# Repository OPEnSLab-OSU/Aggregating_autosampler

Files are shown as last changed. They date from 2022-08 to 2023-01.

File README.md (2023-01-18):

# Aggregating_autosampler
Compositing autosampler using weight based sampling targeted for sewage sampling in manholes. Code originally housed in ADS1232 branch of [SingleSampler repository](https://github.com/OPEnSLab-OSU/SingleSampler) and created using [Kawin Pechetratanapanit's sampler framework](https://github.com/OPEnSLab-OSU/OPEnSamplerFramework).

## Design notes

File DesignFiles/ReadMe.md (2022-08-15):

[Bill of Materials](https://docs.google.com/spreadsheets/d/12LoKV3FAbf4hfWeB7zsqfaazoJ8oWiLxr8qu5_F6xMY/edit?usp=sharing)

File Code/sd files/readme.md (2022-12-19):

Read me for formatting and understanding the data.csv file

data.csv should be opened in Google Sheets or MS Excel (or a similar program) 
for proper readability.

Data.csv logs major milestones in the sampling routine.

The first column of data.csv is the time. It is in unformatted Unix Epoch Time, 
meaning it shows up as a big number representing the number of seconds since 1970.
To convert that big number into a human readable format, make a fourth column that
uses this formula:

=A1/86400+date(1970,1,1)

The second (B) column is the action performed.

Additional columns contain values from the sensors: 
C: Load in grams
D: Temperature in degrees Celsius
E: Pressure in mbar

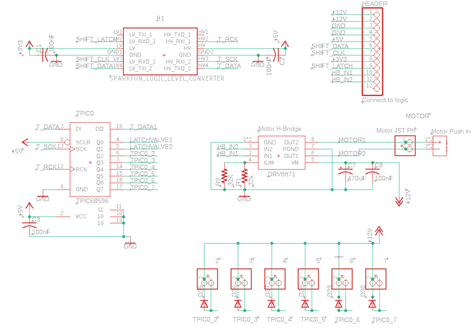
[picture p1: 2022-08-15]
DesignFiles/Power_module_schematic.png

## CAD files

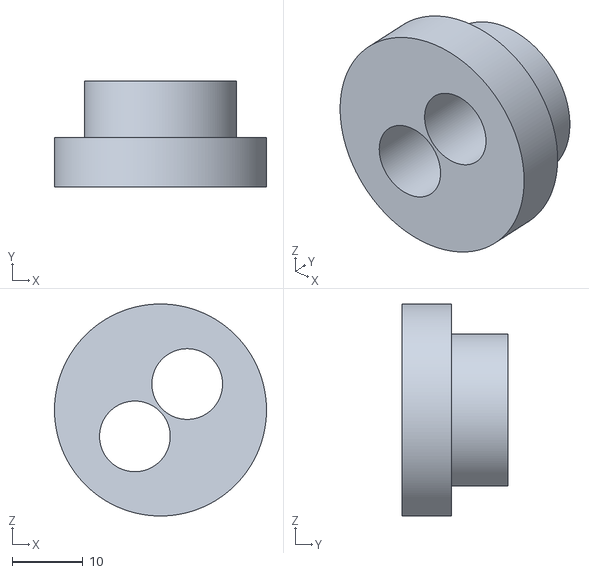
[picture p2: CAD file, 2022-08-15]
DesignFiles/Tube holder.stl
30.0 x 15.0 x 30.0

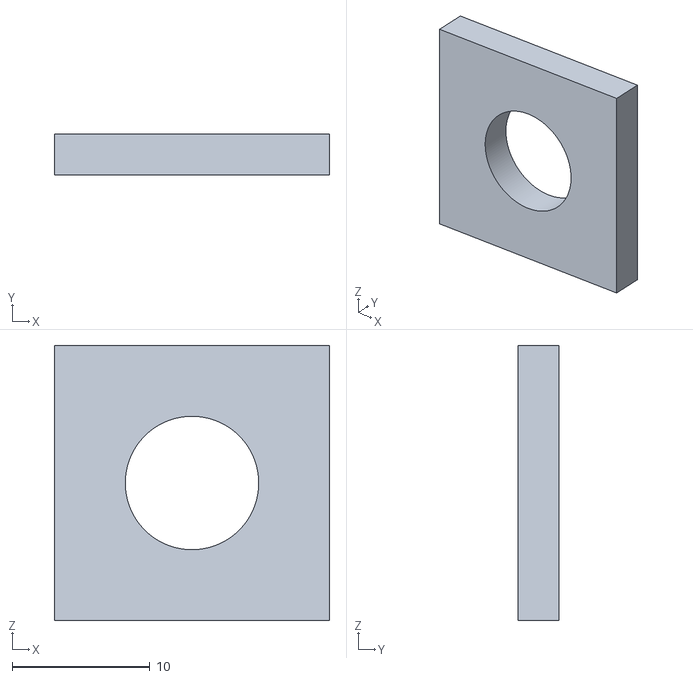
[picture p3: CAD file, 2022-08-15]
DesignFiles/LED Box.stl
20.0 x 3.00 x 20.0

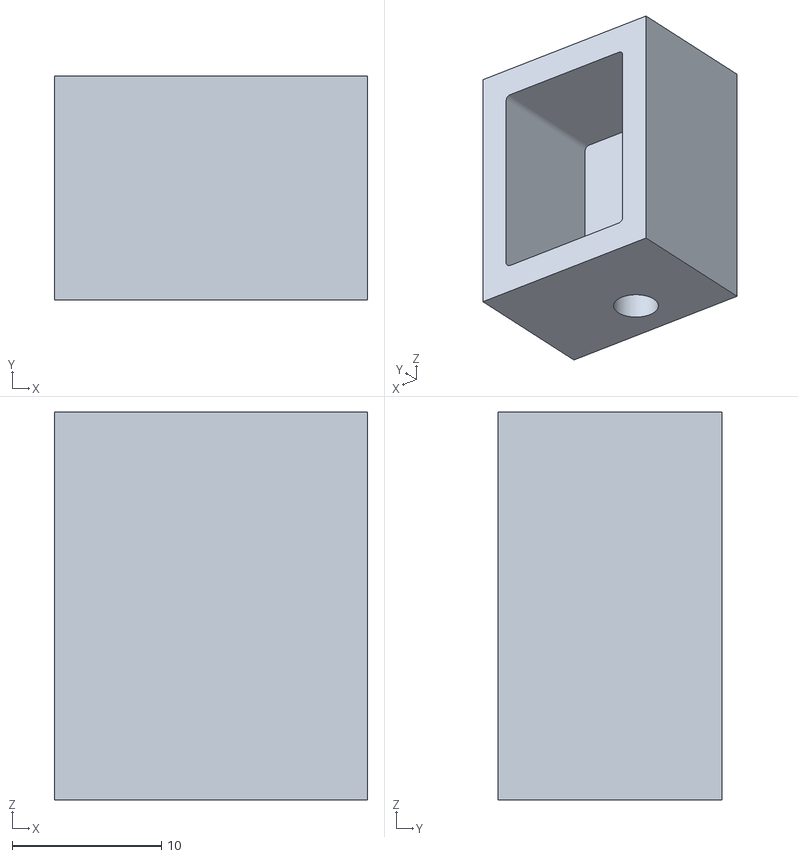
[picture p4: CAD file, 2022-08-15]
DesignFiles/pressure sensor Box.stl
21.0 x 15.0 x 26.0

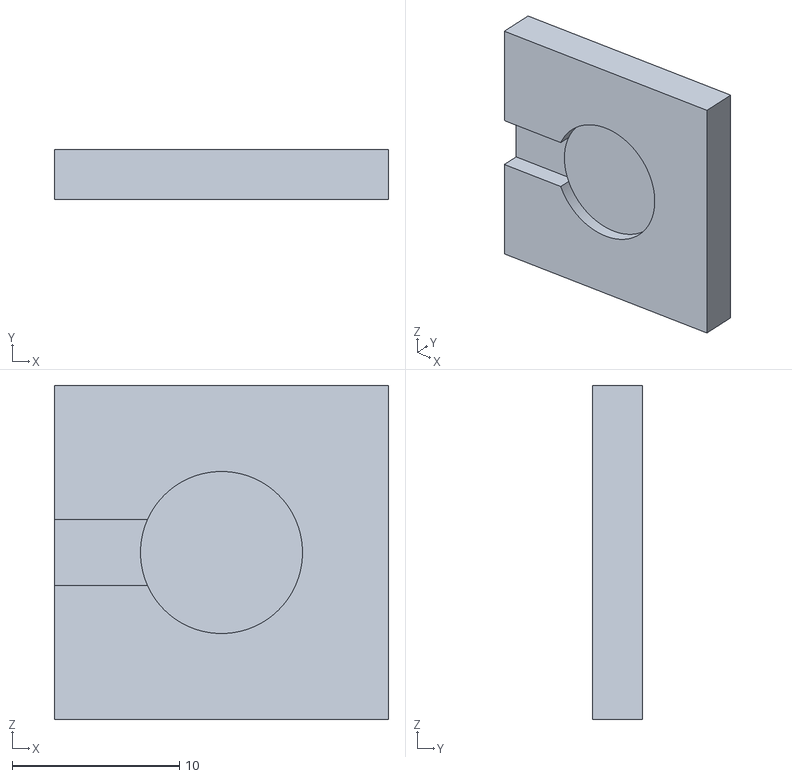
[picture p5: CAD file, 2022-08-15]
DesignFiles/LED Lid.stl
20.0 x 3.00 x 20.0

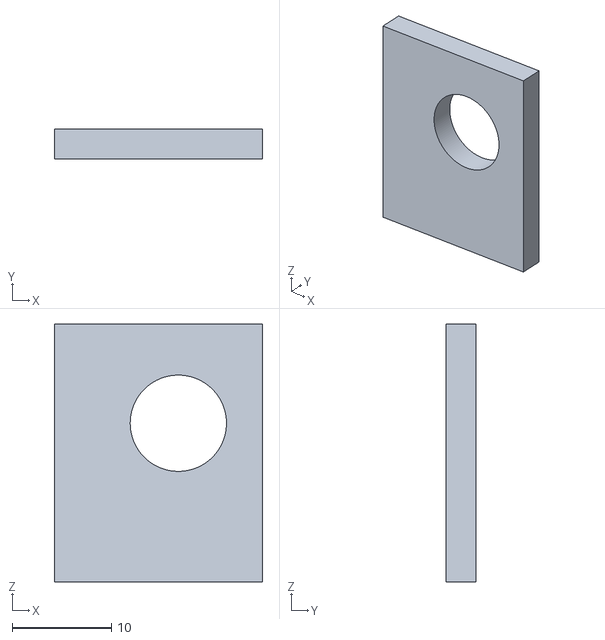
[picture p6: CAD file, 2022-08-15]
DesignFiles/pressure sensor Box lid.stl
21.0 x 3.00 x 26.0

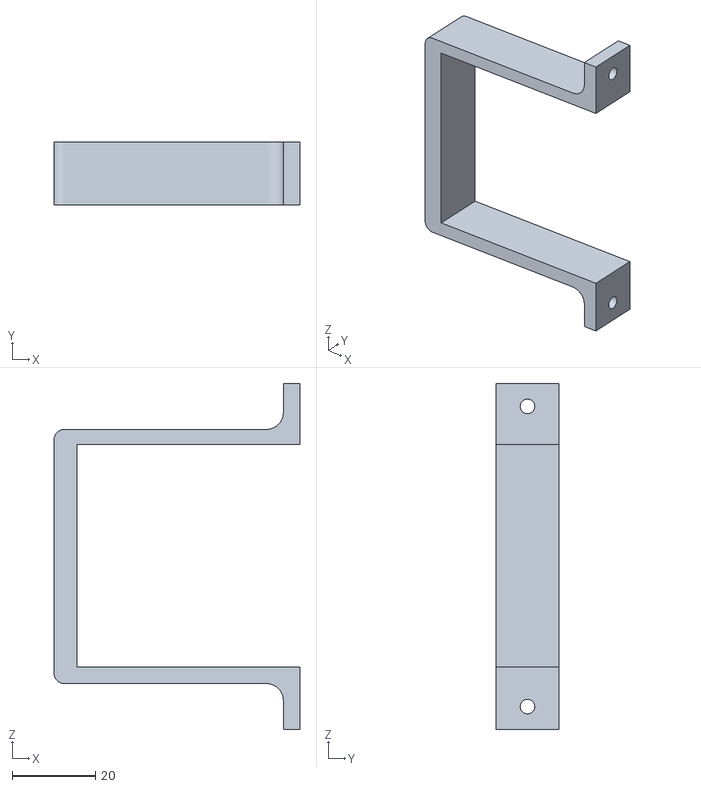
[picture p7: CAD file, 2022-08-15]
DesignFiles/Valve Bracket.stl
59.0 x 15.0 x 83.0

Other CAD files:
DesignFiles/AcrylicCircle.dxf
DesignFiles/Enclosure_insert.dxf
DesignFiles/Enclosure_bottom.dxf

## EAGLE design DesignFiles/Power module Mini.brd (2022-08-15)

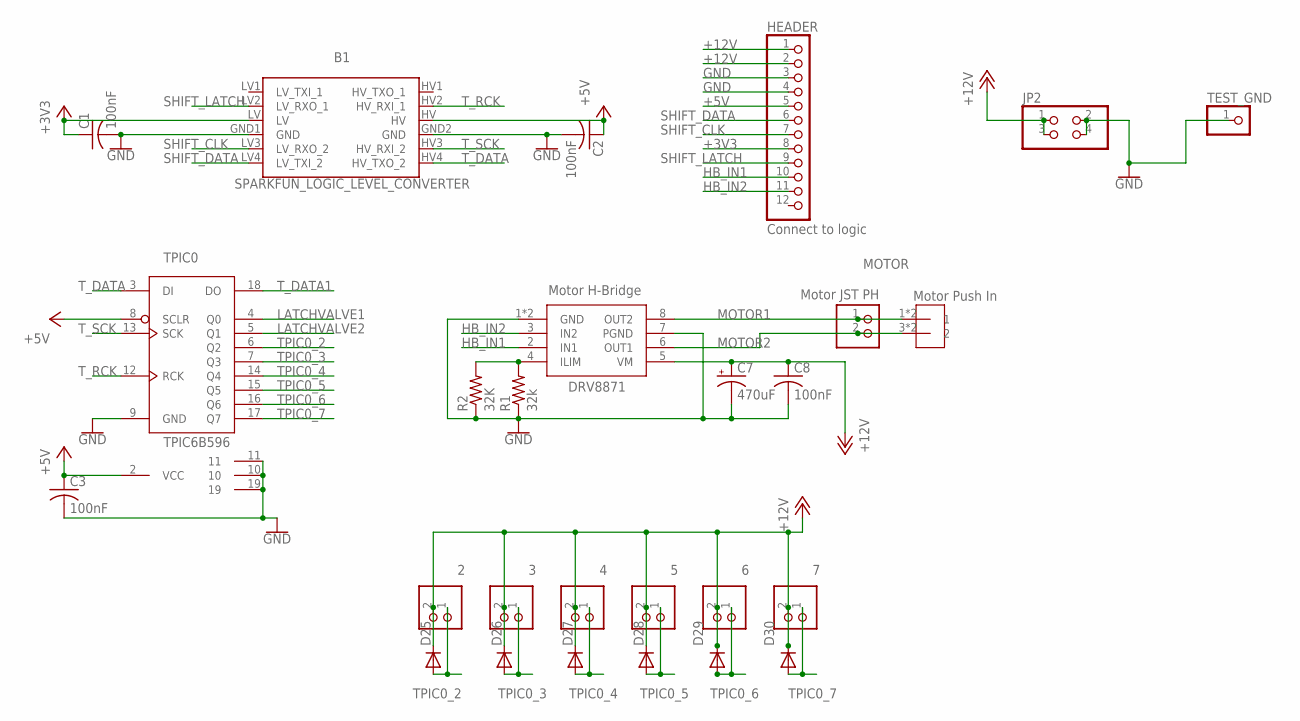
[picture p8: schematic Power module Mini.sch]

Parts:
2, 3, 4, 5, 6, 7: 2.5MM_JST_UP_2POS; JST_2POS_2.5MM_UP
B1: SPARKFUN_LOGIC_LEVEL_CONVERTER
C1, C2, C3, C8: 100nF; C1206
C7: 470uF; 140CLH-0810
D25, D26, D27, D28, D29, D30: DIODESOD-123; SOD-123
DRV8871: Motor H-Bridge; SOP8
HEADER: Connect to logic; 1X12
JP2: PINHD-2X2; 2X02
MOTOR: Motor JST PH; JST_2POS_2.5MM_UP
R1: 32k; 0204/5
R2: 32K; R0805
TEST_GND: PINHD-1X1; 1X01
TPIC0: TPIC6B596; DIP20
U$1: Motor Push In; 3.5MM_DIP2

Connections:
+3V3: B1.LV, C1.1, HEADER.8
+5V: B1.HV, C2.1, C3.1, HEADER.5, TPIC0.2 (VCC), TPIC0.8 (SCLR)
+12V: 2.2, 3.2, 4.2, 5.2, 6.2, 7.2, C7.+, C8.1, D25.C, D26.C, D27.C, D28.C, D29.C, D30.C, DRV8871.5 (VM), HEADER.1, HEADER.2, JP2.1, JP2.3
GND: B1.GND1 (GND), B1.GND2 (GND), C1.2, C2.2, C3.2, C7.-, C8.2, DRV8871.1 (GND), DRV8871.7 (PGND), DRV8871.GND, HEADER.3, HEADER.4, JP2.2, JP2.4, R1.1, R2.1, TEST_GND.1, TPIC0.9 (GND), TPIC0.10, TPIC0.11, TPIC0.19
HB_IN1: DRV8871.2 (IN1), HEADER.10
HB_IN2: DRV8871.3 (IN2), HEADER.11
LATCHVALVE1: TPIC0.4 (Q0)
LATCHVALVE2: TPIC0.5 (Q1)
MOTOR1: DRV8871.8 (OUT2), MOTOR.1, U$1.1, U$1.2 (1)
MOTOR2: DRV8871.6 (OUT1), MOTOR.2, U$1.3 (2), U$1.4 (2)
unnamed: DRV8871.4 (ILIM), R1.2, R2.2
SHIFT_CLK: B1.LV3 (LV_RXO_2), HEADER.7
SHIFT_DATA: B1.LV4 (LV_TXI_2), HEADER.6
SHIFT_LATCH: B1.LV2 (LV_RXO_1), HEADER.9
TPIC0_2: 2.1, D25.A, TPIC0.6 (Q2)
TPIC0_3: 3.1, D26.A, TPIC0.7 (Q3)
TPIC0_4: 4.1, D27.A, TPIC0.14 (Q4)
TPIC0_5: 5.1, D28.A, TPIC0.15 (Q5)
TPIC0_6: 6.1, D29.A, TPIC0.16 (Q6)
TPIC0_7: 7.1, D30.A, TPIC0.17 (Q7)
T_DATA: B1.HV4 (HV_TXO_2), TPIC0.3 (DI)
T_DATA1: TPIC0.18 (DO)
T_RCK: B1.HV2 (HV_RXI_1), TPIC0.12 (RCK)
T_SCK: B1.HV3 (HV_RXI_2), TPIC0.13 (SCK)

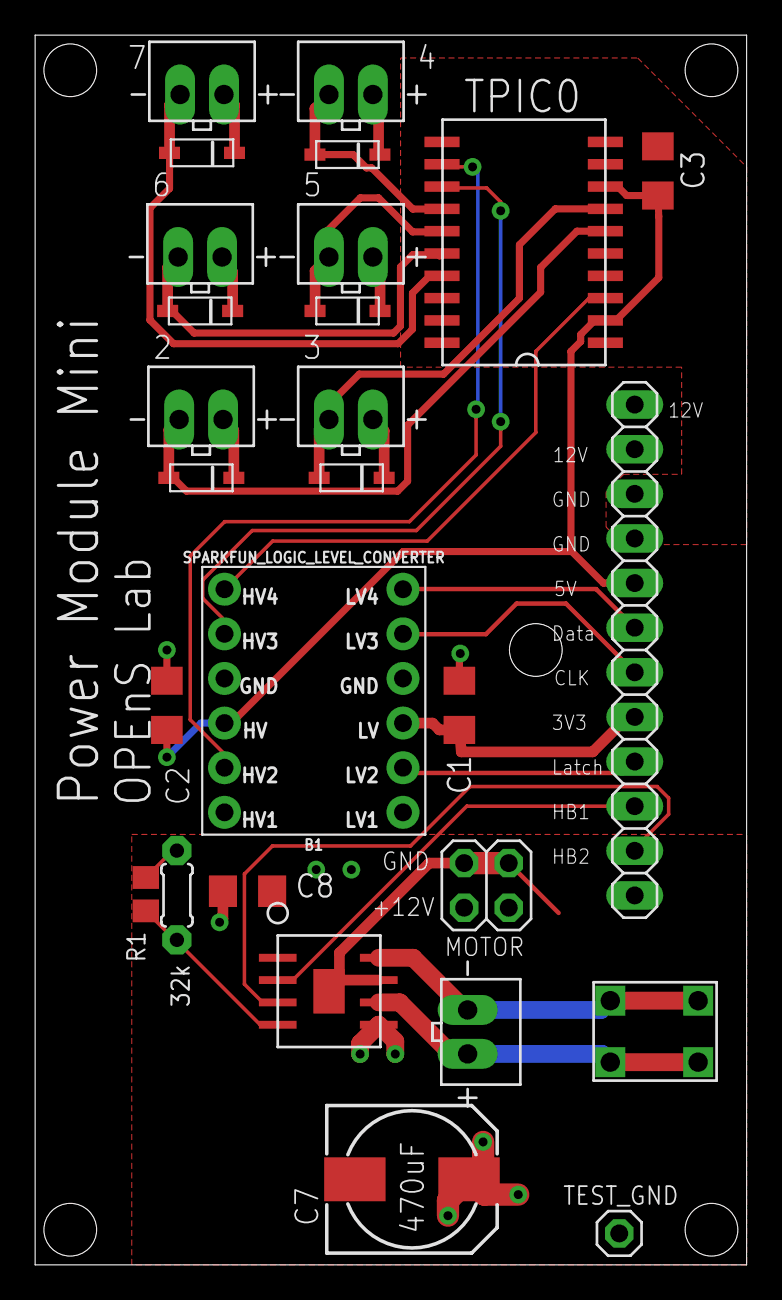
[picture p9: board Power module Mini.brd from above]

Board: 2 copper layers, 40.5 x 70.0 mm, 27 parts (0 on the bottom side), 21 nets.

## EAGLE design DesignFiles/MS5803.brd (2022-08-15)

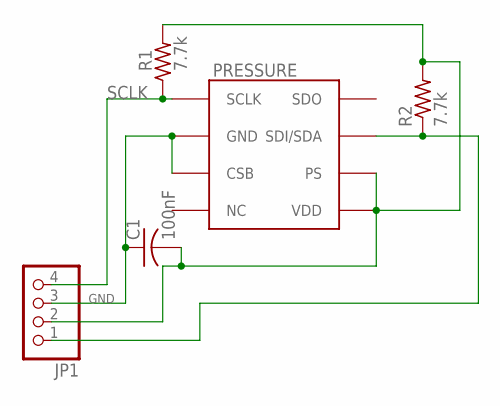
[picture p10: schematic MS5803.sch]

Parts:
C1: 100nF; C0805
JP1: PINHD-1X4; 1X04
PRESSURE: MS5803-01BA; SMD
R1, R2: 7.7k; R0805

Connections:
GND: C1.1, JP1.3, PRESSURE.CSB, PRESSURE.GND
unnamed: C1.2, JP1.2, PRESSURE.PS, PRESSURE.VDD, R1.2, R2.2
unnamed: JP1.1, PRESSURE.SDI/SDA, R2.1
SCLK: JP1.4, PRESSURE.SCLK, R1.1

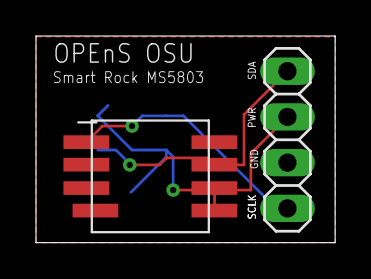
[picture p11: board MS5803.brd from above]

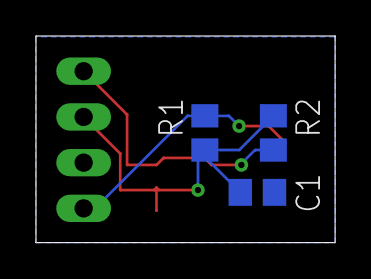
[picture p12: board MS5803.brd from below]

Board: 2 copper layers, 16.6 x 11.5 mm, 5 parts (3 on the bottom side), 4 nets.

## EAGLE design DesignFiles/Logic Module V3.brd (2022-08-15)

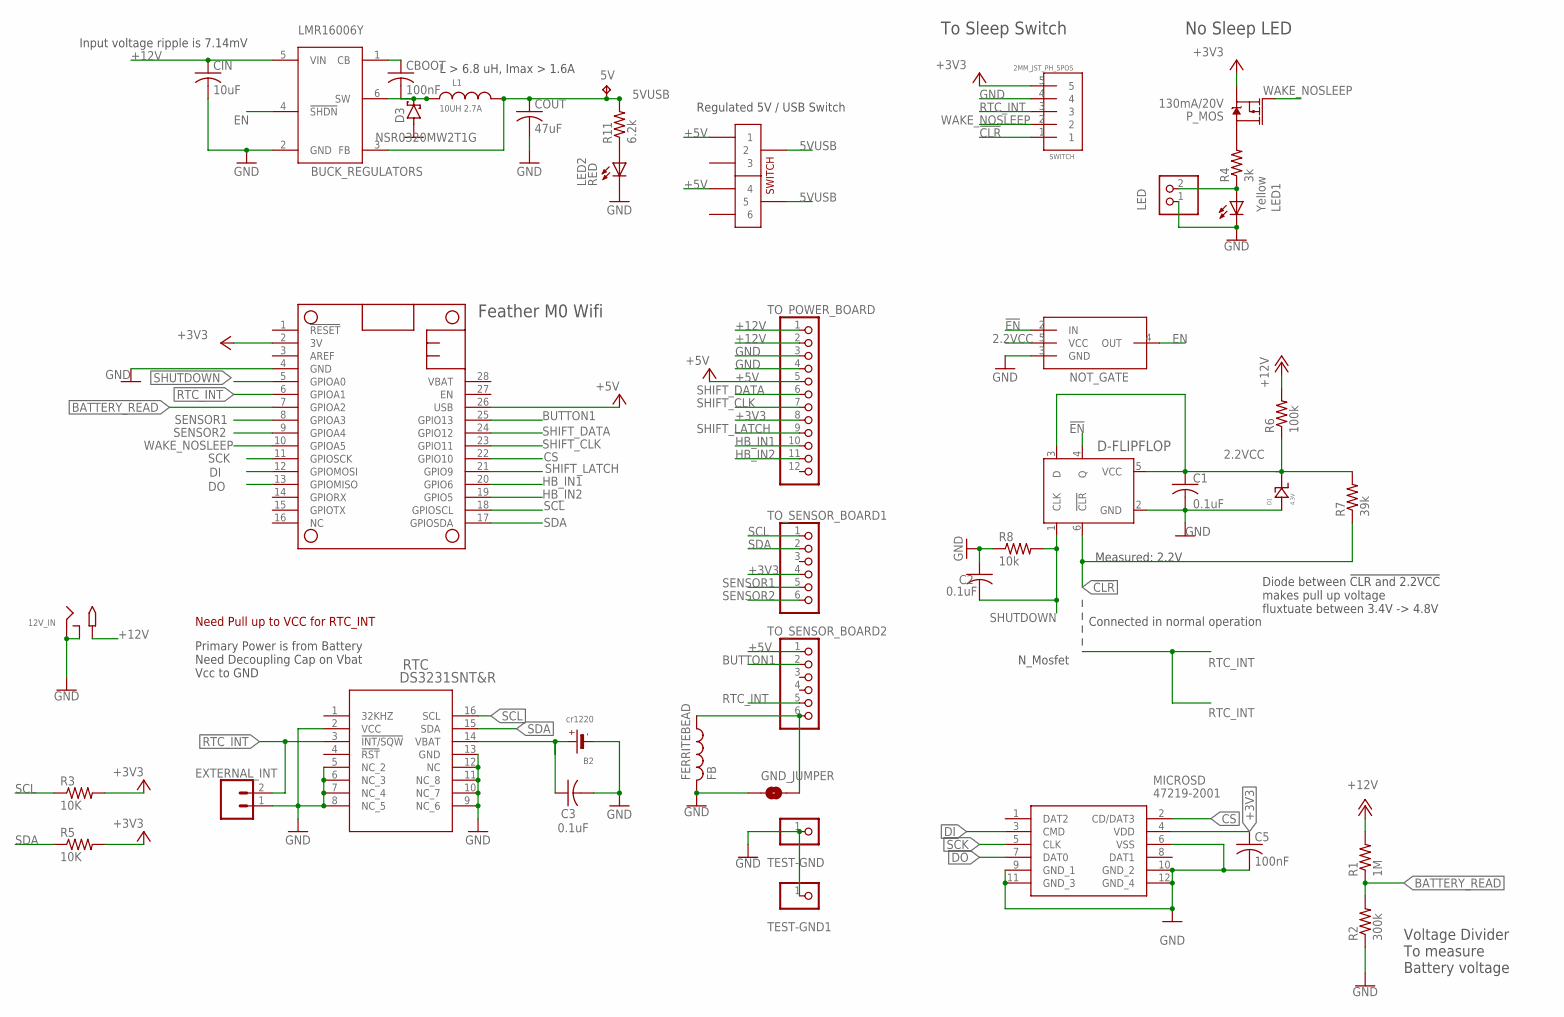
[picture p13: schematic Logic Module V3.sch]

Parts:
5V: TPTP16R; TP16R
12V_IN: 2.1MMJACKSMT; DCJACK_2MM_SMT
B2: cr1220; CR1220-2
C1, C2, C3: 0.1uF; C1206
C5: 100nF; C1206
CBOOT: 100nF; C1206
CIN: 10uF; C1206K
COUT: 47uF; C1206
D1: 4.3V; DO-219AC
D3: NSR0320MW2T1G; SOD323_ST
D-FLIPFLOP: SN74LVC1G175DBVR; DBV6
EXTERNAL_INT: CONN_021X02_NO_SILK; 1X02_NO_SILK
FERRITEBEAD: FB
GND_JUMPER: JUMPER-SMT_2_NO_NO-SILK; SMT-JUMPER_2_NO_NO-SILK
L1: 10UH 2.7A; WE-MAPI_40XX
LED: 2.5MM_JST_UP_2POS; JST_2POS_2.5MM_UP
LED1: Yellow; CHIPLED_0805
LED2: RED; CHIPLED_0805
MICROSD: 47219-2001; 472192001
MS1: FEATHERWING
P_MOS: 130mA/20V; SOT23-3
R1: 1M; R1206
R2: 300k; R1206
R3, R5: 10K; R1206
R4: 3k; R1206
R6: 100k; R1206
R7: 39k; R1206
R8: 10k; R1206
R11: 6.2k; RES_1206
RTC: DS3231SNT&R; 21-0042B_16
SWITCH: 2MM_JST_PH_5POS; 2MM_5POS_HEADER
TEST-GND, TEST-GND1: PINHD-1X1; 1X01
TO_POWER_BOARD: PINHD-1X12; 1X12
TO_SENSOR_BOARD1, TO_SENSOR_BOARD2: PINHD-1X6CB; 1X06-CLEANBIG
U$1: 2PDT_SWITCHJS-SMD; JS-DPDT-SMD
U$3: NOT_GATE; SOT753
VREG: BUCK_REGULATORS; SOT23-6

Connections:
2.2VCC: C1.1, D1.FNT, D-FLIPFLOP.3 (D), D-FLIPFLOP.5 (VCC), R6.1, R7.2, U$3.5 (VCC)
5VUSB: 5V.TP, COUT.1, L1.2, R11.2, U$1.P$2 (2), U$1.P$5 (5), VREG.3 (FB)
!CLR: D-FLIPFLOP.6 (!CLR), R7.1, SWITCH.1
!EN: D-FLIPFLOP.4 (Q), U$3.2 (IN)
+3V3: C5.1, MICROSD.4 (VDD), MS1.2 (3V), P_MOS.2 (S), R3.2, R5.2, SWITCH.5, TO_POWER_BOARD.8, TO_SENSOR_BOARD1.4
+5V: MS1.26 (USB), TO_POWER_BOARD.5, TO_SENSOR_BOARD2.1, U$1.P$1 (1), U$1.P$4 (4)
+12V: 12V_IN.PWR2 (TIP), CIN.1, R1.2, R6.2, TO_POWER_BOARD.1, TO_POWER_BOARD.2, VREG.5 (VIN)
BATTERY_READ: MS1.7 (GPIOA2), R1.1, R2.2
BUTTON1: MS1.25 (GPIO13), TO_SENSOR_BOARD2.2
CS: MICROSD.2 (CD/DAT3), MS1.22 (GPIO10)
DI: MICROSD.3 (CMD), MS1.12 (GPIOMOSI)
DO: MICROSD.7 (DAT0), MS1.13 (GPIOMISO)
EN: U$3.4 (OUT), VREG.4 (!SHDN)
GND: 12V_IN.GND (RING), 12V_IN.GNDBREAK (RING_SW), B2.-, C1.2, C2.1, C3.2, C5.2, CIN.2, COUT.2, D1.BCK, D3.A, D-FLIPFLOP.2 (GND), EXTERNAL_INT.1, FERRITEBEAD.P$2 (2), GND_JUMPER.1, LED.1, LED1.C, LED2.C, MICROSD.6 (VSS), MICROSD.9 (GND_1), MICROSD.10 (GND_2), MICROSD.11 (GND_3), MICROSD.12 (GND_4), MS1.4 (GND), R2.1, R8.1, RTC.2 (VCC), RTC.5 (NC_2), RTC.6 (NC_3), RTC.7 (NC_4), RTC.8 (NC_5), RTC.9 (NC_6), RTC.10 (NC_7), RTC.11 (NC_8), RTC.12 (NC), RTC.13 (GND), SWITCH.4, TEST-GND.1, TEST-GND1.1, TO_POWER_BOARD.3, TO_POWER_BOARD.4, U$3.3 (GND), VREG.2 (GND)
HB_IN1: MS1.20 (GPIO6), TO_POWER_BOARD.10
HB_IN2: MS1.19 (GPIO5), TO_POWER_BOARD.11
unnamed: B2.+, C3.1, RTC.14 (VBAT)
unnamed: P_MOS.3 (D), R4.2
unnamed: LED.2, LED1.A, R4.1
unnamed: FERRITEBEAD.P$1 (1), GND_JUMPER.2, TO_SENSOR_BOARD2.6
unnamed: LED2.A, R11.1
unnamed: CBOOT.1, VREG.1 (CB)
unnamed: CBOOT.2, D3.C, L1.1, VREG.6 (SW)
RTC_INT: EXTERNAL_INT.2, MS1.6 (GPIOA1), RTC.3 (!INT/SQW), SWITCH.3, TO_SENSOR_BOARD2.5
SCK: MICROSD.5 (CLK), MS1.11 (GPIOSCK)
SCL: MS1.18 (GPIOSCL), R3.1, RTC.16 (SCL), TO_SENSOR_BOARD1.1
SDA: MS1.17 (GPIOSDA), R5.1, RTC.15 (SDA), TO_SENSOR_BOARD1.2
SENSOR1: MS1.8 (GPIOA3), TO_SENSOR_BOARD1.5
SENSOR2: MS1.9 (GPIOA4), TO_SENSOR_BOARD1.6
SHIFT_CLK: MS1.23 (GPIO11), TO_POWER_BOARD.7
SHIFT_DATA: MS1.24 (GPIO12), TO_POWER_BOARD.6
SHIFT_LATCH: MS1.21 (GPIO9), TO_POWER_BOARD.9
SHUTDOWN: C2.2, D-FLIPFLOP.1 (CLK), MS1.5 (GPIOA0), R8.2
WAKE_NOSLEEP: MS1.10 (GPIOA5), P_MOS.1 (G), SWITCH.2

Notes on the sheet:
No Sleep LED
Feather M0 Wifi
To Sleep Switch
Voltage Divider To measure Battery voltage
Primary Power is from Battery Need Decoupling Cap on Vbat Vcc to GND
Measured: 2.2V
Connected in normal operation
N_Mosfet
Diode between !CLR and 2.2VCC makes pull up voltage fluxtuate between 3.4V -> 4.8V
Input voltage ripple is 7.14mV
L > 6.8 uH, Imax > 1.6A
Regulated 5V / USB Switch
Need Pull up to VCC for RTC_INT

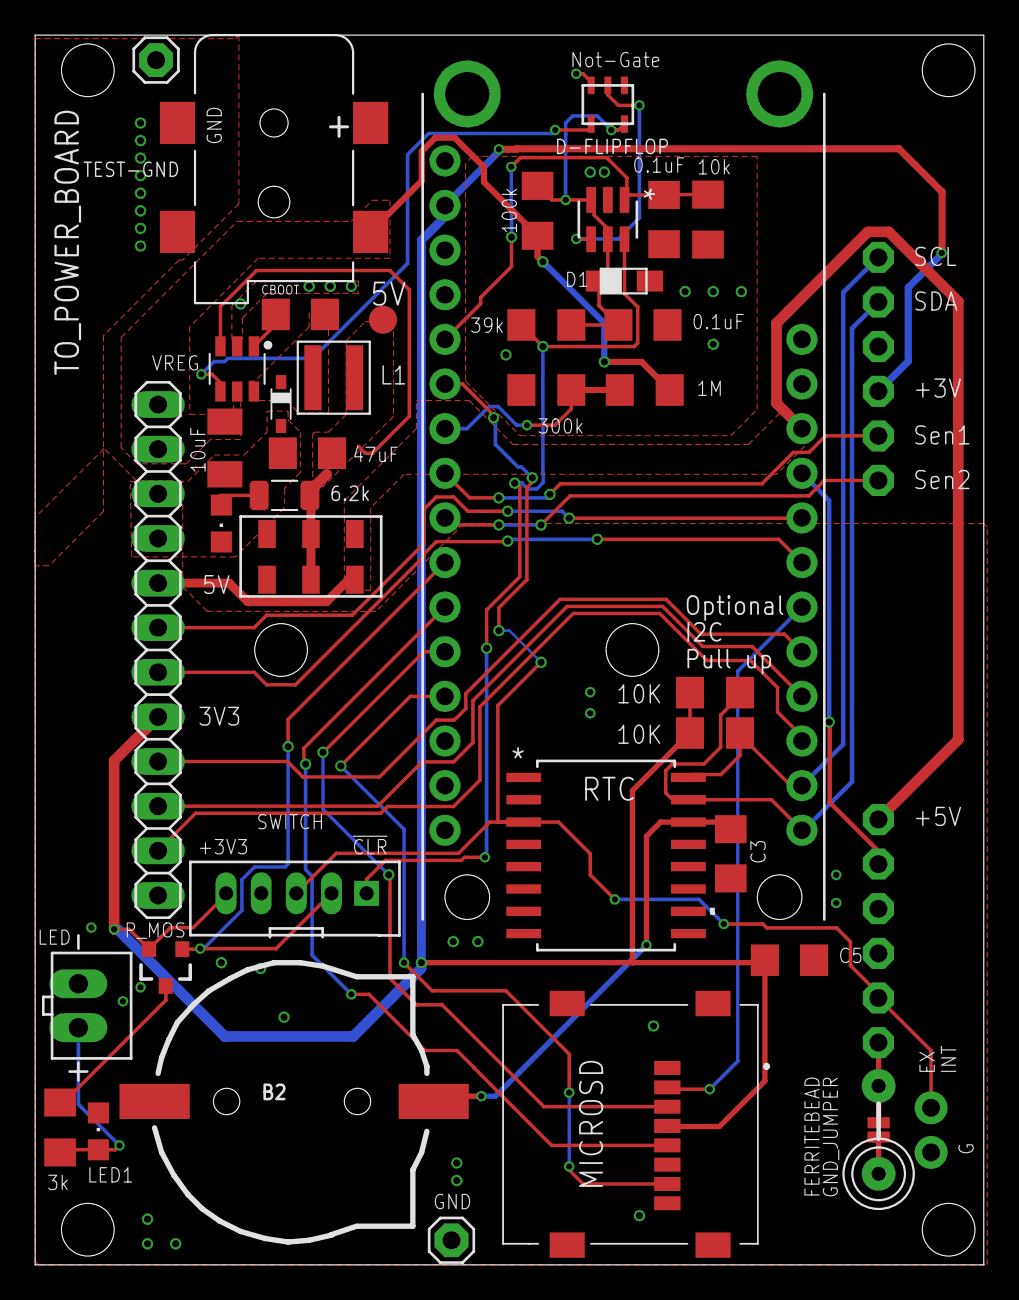
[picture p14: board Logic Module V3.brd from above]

Board: 2 copper layers, 54.0 x 70.0 mm, 43 parts (1 on the bottom side), 34 nets.

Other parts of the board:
U$2: OPENS-LOGO

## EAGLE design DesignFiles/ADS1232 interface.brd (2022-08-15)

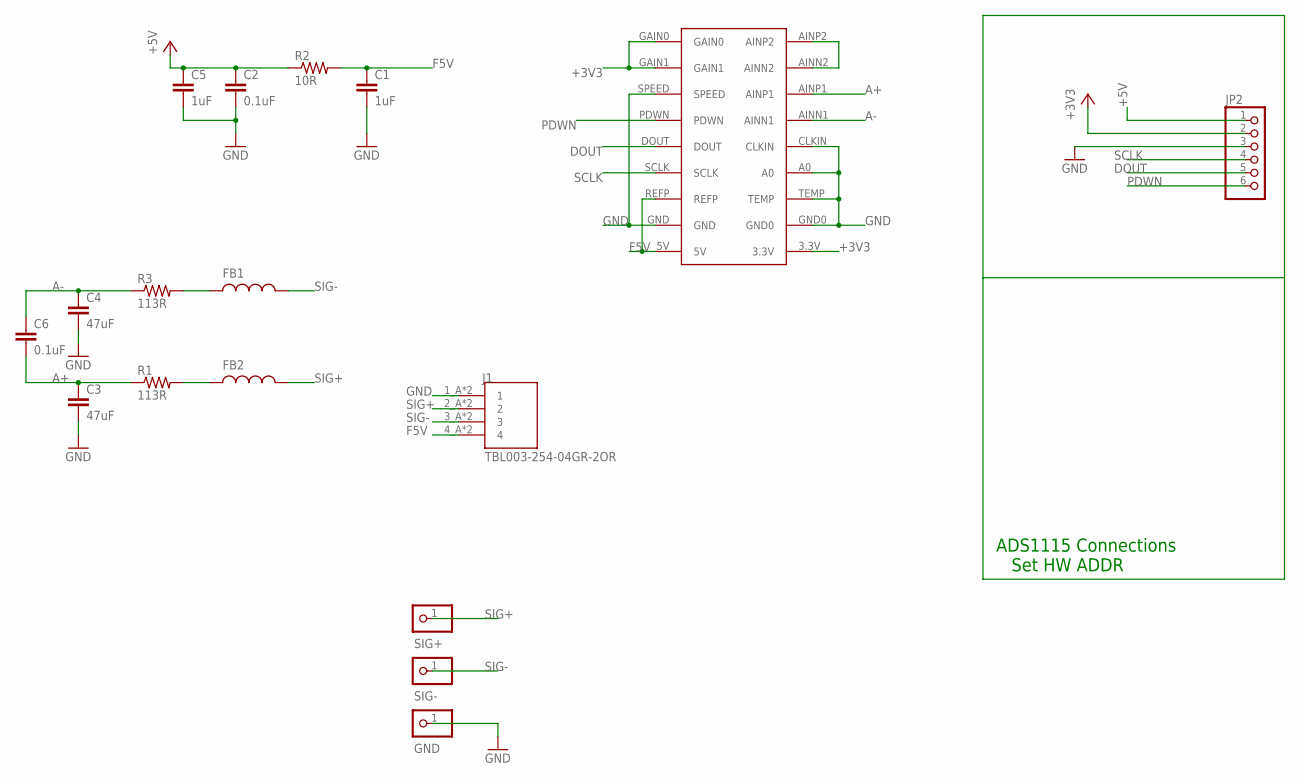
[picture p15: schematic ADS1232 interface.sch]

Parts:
ADS1232: ADS1232
C1, C5: 1uF; C0805
C2, C6: 0.1uF; C0805
C3, C4: 47uF; C0805
FB1, FB2: WE-RFI_0805A_744760282A; WE-RFI_0805A
GND: PINHD-1X1; 1X01
J1: TBL003-254-04GR-2OR; CUI_TBL003-254-04GR-2OR
JP2: PINHD-1X6; 1X06
R1, R3: 113R; R0805
R2: 10R; R0805
SIG+: PINHD-1X1; 1X01
SIG-: PINHD-1X1; 1X01

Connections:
+3V3: ADS1232.3.3V, ADS1232.GAIN0, ADS1232.GAIN1, JP2.2
+5V: C2.1, C5.1, JP2.1, R2.1
A+: ADS1232.AINP1, C3.1, C6.2, R1.1
A-: ADS1232.AINN1, C4.1, C6.1, R3.1
DOUT: ADS1232.DOUT, JP2.5
F5V: ADS1232.5V, ADS1232.REFP, C1.1, J1.4_A (4), J1.4_B (4), R2.2
GND: ADS1232.A0, ADS1232.AINN2, ADS1232.AINP2, ADS1232.CLKIN, ADS1232.GND, ADS1232.GND0, ADS1232.SPEED, ADS1232.TEMP, C1.2, C2.2, C3.2, C4.2, C5.2, GND.1, J1.1_A (1), J1.1_B (1), JP2.3
unnamed: FB1.1, R3.2
unnamed: FB2.1, R1.2
PDWN: ADS1232.PDWN, JP2.6
SCLK: ADS1232.SCLK, JP2.4
SIG+: FB2.2, J1.2_A (2), J1.2_B (2), SIG+.1
SIG-: FB1.2, J1.3_A (3), J1.3_B (3), SIG-.1

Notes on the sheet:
ADS1115 Connections Set HW ADDR

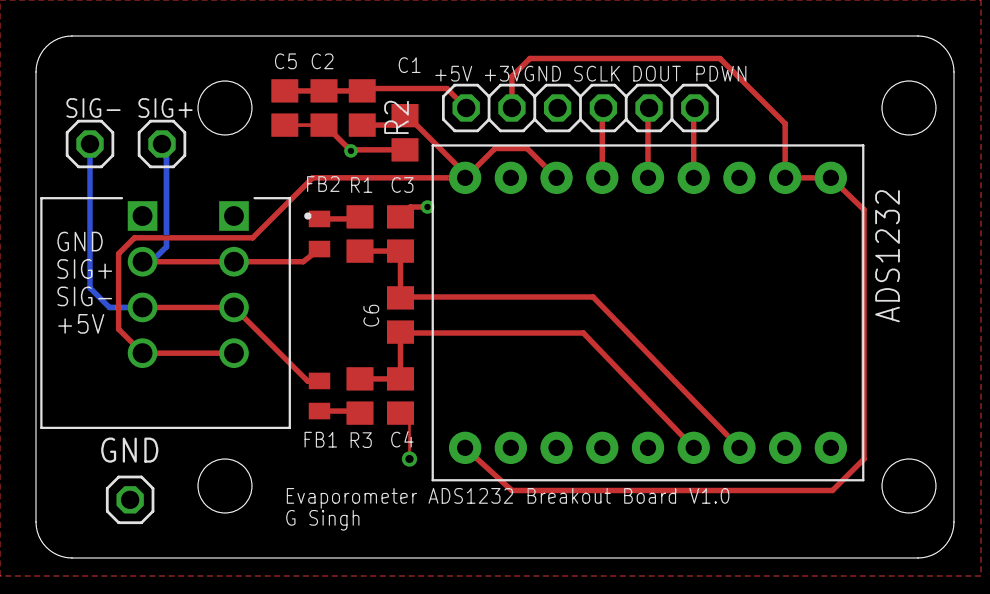
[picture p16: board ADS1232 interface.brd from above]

Board: 2 copper layers, 51.0 x 29.0 mm, 17 parts (0 on the bottom side), 13 nets.

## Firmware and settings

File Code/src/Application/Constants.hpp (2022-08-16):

#pragma once

namespace HardwarePins {
	constexpr int SHFT_REG_LATCH = 9;
	constexpr int SHFT_REG_CLOCK = 11;
	constexpr int SHFT_REG_DATA	 = 12;
	constexpr int MOTOR_REVERSE	 = 5;
	constexpr int MOTOR_FORWARDS = 6;
	constexpr int RUN_BUTTON	 = A5;
	constexpr int CLEAN_BUTTON	 = 13;
	constexpr int SD			 = 10;
	constexpr int DOUT			 = A3;
	constexpr int SCLK			 = 0;
	constexpr int PDWN			 = 1;
	constexpr int PIXEL		  	 = A4;
}  // namespace HardwarePins

namespace DefaultTimes {
	const int FLUSH_TIME  = 50;
	const int SAMPLE_TIME = 60;
	const int IDLE_TIME	  = 3600 - FLUSH_TIME - SAMPLE_TIME;
	const int SETUP_TIME  = 0;
	const int FILL_TIME = 20;
}  // namespace DefaultTimes

namespace DefaultTimesClean {
	const int SAMPLE_TIME = 5;
	const int IDLE_TIME	  = 0;
	const int FLUSH_TIME  = 20;
}  // namespace DefaultTimesClean

namespace DefaultTimesButton {
	const unsigned long DEBOUNCE_TIME = 100;
}

namespace TPICDevices {
	constexpr int INTAKE_POS  = 0;
	constexpr int INTAKE_NEG  = 1;
	constexpr int FLUSH_VALVE = 3;
	constexpr int WATER_VALVE = 2;
}  // namespace TPICDevices

namespace DefaultPressures {
	constexpr int MIN_PRESSURE = 400;	// 600
	constexpr int MAX_PRESSURE = 1300;	// 990
}  // namespace DefaultPressures

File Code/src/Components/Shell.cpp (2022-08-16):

#include <Components/Shell.hpp>
#include <Application/Application.hpp>
#include <Application/Constants.hpp>
#include <KPFoundation.hpp>
#include <SD.h>
#include <ArduinoJson.h>
#include <time.h>
#include <sstream>
#include <String>
//#include <FileIO/SerialSD.hpp>
#define cmnd_lambda [](Application & app, const std::string * args)
#define CALL		(app, args)

namespace Utility {
	// returns true if str is a pos int
	// assumes string correctness
	bool is_posint(const char * str) {
		for (int i = 0; str[i] != '\0'; ++i) {
			if (str[i] > '9' || str[i] < '0') {
				return false;
			}
		}
		return true;
	}

	// returns true if str is a pos int
	// displays a msg if it isn't
	bool msg_posint(const char * str, int arg) {
		bool posint = is_posint(str);
		if (!posint) {
			Serial.print("Error: argument ");
			Serial.print(arg);
			Serial.print(" needs to be a pos int.");
		}
		return posint;
	}

	std::string readEntireFile(File & file) {
		std::string contents;
		while (-1 != file.peek()) {
			contents.push_back(file.read());
		}
		return contents;
	}
}  // namespace Utility

void Shell::runFunction(const std::string * args, const unsigned short length) {
	if (commands.find(args[0]) != commands.end()) {
		if (length - 1 == commands.at(args[0]).n_args) {
			Application & app = *static_cast<Application *>(controller);
			commands.at(args[0]).function(app, args);
		} else {
			Serial.print("Bad arguments\n");
		}
	} else {
		Serial.print("Bad command.\n");
	}
}

/*
	addFunction(
		"name",
		n args,
		cmnd_lambda { function });

	You will have access to app and args[]. args[0] should always
	be the same as the name of the command. They are C++ strings
*/

void Shell::setup() {
	// run button
	addFunction(
		"sample_button_press",
		0,
		cmnd_lambda { app.sm.begin(); });

	// clean button
	addFunction(
		"clean_button_press",
		0,
		cmnd_lambda { app.csm.begin(); });
	
	// halt the machine in the sample state
	addFunction(
		"sample_halt",
		0,
		cmnd_lambda { app.sm.halt(); });

	// halt the clean state machine
	addFunction(
		"clean_halt",
		0,
		cmnd_lambda { app.csm.halt(); });

	// halt all state machines
	addFunction(
		"halt",
		0,
		cmnd_lambda {
			app.sm.halt();
			app.csm.halt();
		});

	// print free ram
	addFunction(
		"mem",
		0,
		cmnd_lambda { Serial.println(free_ram()); });

	addFunction(
		"state_read",
		0,
		cmnd_lambda {
			File file = SD.open("state.js", FILE_READ);
			Serial.println(Utility::readEntireFile(file).c_str());
			file.close();
		});

	addFunction(
		"check_sample_flush_time",
		0,
		cmnd_lambda {
			Serial.println(app.sm.getState<SampleStateFlush>(SampleStateNames::FLUSH).time);
		});
	
	//Set time in Unix Epoch time - number of seconds since 1/1/1970 e.g. https://www.epochconverter.com/
	addFunction(
		"set_time",
		1,
		cmnd_lambda {
			if (Utility::msg_posint(args[1].c_str(), 1)) {
				app.clock.set(std::stoi(args[1]));
			}
		});
	
	//unix epoch time - seconds since January 1, 1970
	addFunction(
		"get_time",
		0,
		cmnd_lambda {
			const auto timenow = now();
			char time_string[50];
			sprintf(time_string, "%u", timenow);
			Serial.println(time_string);

		});

	addFunction(
		"get_pressure",
		0,
		cmnd_lambda { Serial.println(app.pressure_sensor.getPressure()); });

	addFunction(
		"get_load",
		1,
		cmnd_lambda { Serial.println(app.load_cell.getLoad(stoi(args[1]))); });

	addFunction(
		"get_tared_load",
		1,
		cmnd_lambda { Serial.println(app.load_cell.getTaredLoad(stoi(args[1]))); });

	addFunction(
		"volt_load",
		0,
		cmnd_lambda { Serial.println(app.load_cell.getVoltage()); });

	addFunction(
		"sample_no_runs",
		1,
		cmnd_lambda {
			const char * loc[2] = {"sample", "last_cycle"};
			app.reWrite(loc, app.sm.last_cycle, std::stoi(args[1]));
		});

	addFunction(
		"sample_flush_time",
		1,
		cmnd_lambda {
			const char * loc[2] = {"sample", "flush_time"};
			app.reWrite(loc,
				app.sm.getState<SampleStateFlush>(SampleStateNames::FLUSH).time,
				std::stoi(args[1]));
		});

	addFunction(
		"sample_fill_time",
		1,
		cmnd_lambda {
			const char * loc[2] = {"sample", "fill_time"};
			app.reWrite(loc,
				app.sm.getState<SampleStateFlush>(SampleStateNames::FILL_TUBE).time,
				std::stoi(args[1]));
		});	

	addFunction(
		"sample_sample_time",
		1,
		cmnd_lambda {
			const char * loc[2] = {"sample", "sample_time"};
			app.reWrite(loc,
				app.sm.getState<SampleStateSample>(SampleStateNames::SAMPLE).time,
				std::stoi(args[1]));
		});

	addFunction(
		"sample_sample_mass",
		1,
		cmnd_lambda {
			const char * loc[2] = {"sample", "sample_mass"};
			app.reWrite(loc,
				app.sm.getState<SampleStateSample>(SampleStateNames::SAMPLE).mass,
				std::stoi(args[1]));
		});

	addFunction(
		"sample_idle_time",
		1,
		cmnd_lambda {
			const char * loc[2] = {"sample", "idle_time"};
			app.reWrite(loc,
				app.sm.getState<SampleStateIdle>(SampleStateNames::IDLE).time,
				std::stoi(args[1]));
		});

	addFunction(
		"sample_between_time",
		1,
		cmnd_lambda {
			const char * loc[2] = {"sample", "idle_time"};
			app.reWrite(loc,
				app.sm.getState<SampleStateIdle>(SampleStateNames::IDLE).time,
				std::stoi(args[1])
					- app.sm.getState<SampleStateOnramp>(SampleStateNames::ONRAMP).time
					- app.sm.getState<SampleStateFlush>(SampleStateNames::FLUSH).time
					- app.sm.getState<SampleStateSample>(SampleStateNames::SAMPLE).time);
		});

	addFunction(
		"sample_setup_time",
		1,
		cmnd_lambda {
			const char * loc[2] = {"sample", "setup_time"};
			app.reWrite(loc,
				app.sm.getState<SampleStateSetup>(SampleStateNames::SETUP).time,
				std::stoi(args[1]));
		});

	addFunction(
		"clean_sample_time",
		1,
		cmnd_lambda {
			const char * loc[2] = {"clean", "sample_time"};
			app.reWrite(loc,
				app.csm.getState<CleanStateSample>(CleanStateNames::SAMPLE).time,
				std::stoi(args[1]));
		});

	addFunction(
		"clean_idle_time",
		1,
		cmnd_lambda {
			const char * loc[2] = {"clean", "idle_time"};
			app.reWrite(loc,
				app.csm.getState<CleanStateIdle>(CleanStateNames::IDLE).time,
				std::stoi(args[1]));
		});

	addFunction(
		"clean_flush_time",
		1,
		cmnd_lambda {
			const char * loc[2] = {"clean", "flush_time"};
			app.reWrite(loc,
				app.csm.getState<CleanStateFlush>(CleanStateNames::FLUSH).time,
				std::stoi(args[1]));
		});

	addFunction(
		"sample_setup_tod_enabled",
		1,
		cmnd_lambda {
			const char * loc[2] = {"sample", "setup_tod_enabled"};
			app.reWrite(loc,
				app.sm.getState<SampleStateSetup>(SampleStateNames::SETUP).tod_enabled,
				std::stoi(args[1]));
		});
	addFunction(
		"sample_setup_tod",
		1,
		cmnd_lambda {
			const char * loc[2] = {"sample", "setup_tod"};
			app.reWrite(loc,
				app.sm.getState<SampleStateSetup>(SampleStateNames::SETUP).tod,
				std::stoi(args[1]));
		});
	addFunction(
		"min_pressure",
		1,
		cmnd_lambda {
			const char * loc[2] = {"pressure", "min_pressure"};
			app.reWrite(loc, app.pressure_sensor.min_pressure, std::stoi(args[1]));
		});
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

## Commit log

2022-08-15 Formatted for publication
    Added read me and put in folders
    [ADS1232 interface.brd, ADS1232 interface.sch, AcrylicCircle.dxf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]
2022-08-16 Added pressure print at end of cycle
    re-arranged other prints to have cycle number last
2022-08-16 Fixed pressure print message
2022-08-16 Wt_offset option for different samplers
2022-12-20 Added enclosure drawings
    [Enclosure_bottom.dxf, Enclosure_insert.dxf]

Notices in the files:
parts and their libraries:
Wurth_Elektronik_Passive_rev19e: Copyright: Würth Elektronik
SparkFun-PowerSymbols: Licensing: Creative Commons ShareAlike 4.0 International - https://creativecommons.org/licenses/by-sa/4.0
